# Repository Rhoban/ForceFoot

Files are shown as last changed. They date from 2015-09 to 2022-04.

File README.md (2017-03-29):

# Force foot

**Note that this is the v2 version, you can have a look at the v1 branch for
the previous release**

Here is a design of a robot foot using strain gauges as force sensors.
It was used by the Rhoban Football Club (France) during the RoboCup 2016.

If you have any question feel free to contact team@rhoban.com to ask it,
or open an issue on this repository.

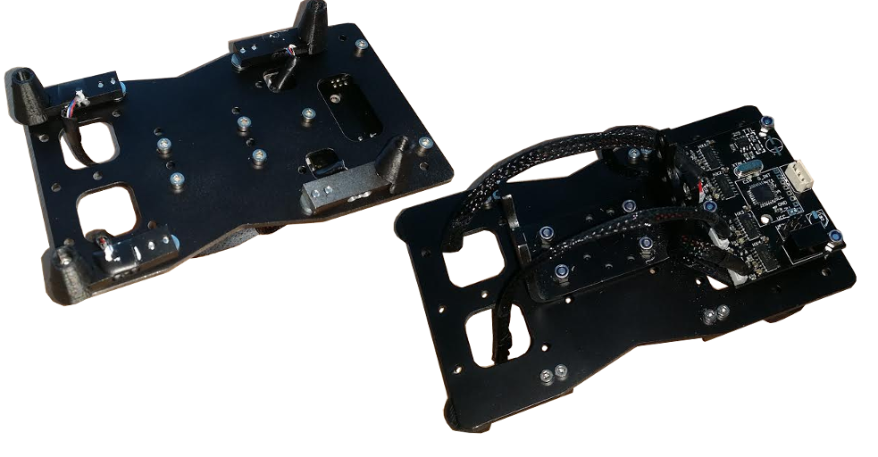
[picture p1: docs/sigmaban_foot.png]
force foot


## Repository contents

Here are the repository contents, you can click on below links to get the documentation:

* A [**mechanical design**](3d) suitable for Rhoban robots, that can be a good base
  to be adapted to fit your needs;
* Schematics for an  [**electronics board**](electronics) containing all the components to get
  the values from the sensors and communicate them through dynamixel;
* A [**firmware**](firmware) for the controller that is on the electronics.

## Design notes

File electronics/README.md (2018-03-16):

# Electronics

Here you'll find the schematics and (auto)routed board for sampling the gauge and communicate
through the dynamixel bus.

## Options

Some optional resistors on this board can be used to support dynamixel TTL/485 and 3/4 wire
gauges:

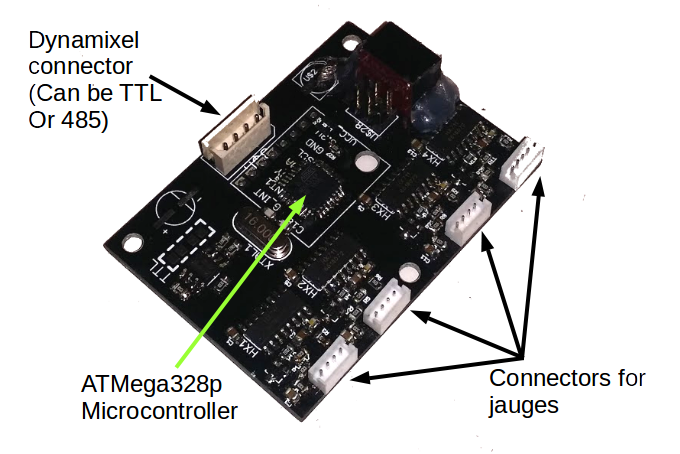
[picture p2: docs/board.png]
optional features


### Dynamixel RS485 or TTL

The two resistors (see yellow zones above) are only required if you want to use TTL Dynamixel.
In this case, you can solder a 3-pin connector on the dynamixel zone and it will do the job.

Actually, the A pin of the RS485 transciever is exactly the same as TTL when driving the line.
this change brings the B pin at VCC/2 (which should be 2.5V), so that when listening an high
A is 2.5V above B and a low A is 2.5V below B, which meets the RS485 requirements and makes
the MAX485 (or ST485) chip able to listen TTL, while perfectly respecting its specifications.

### 3-wire or 4-wire gauges

There is two main kind of mounting, half-bridges, which looks like that:

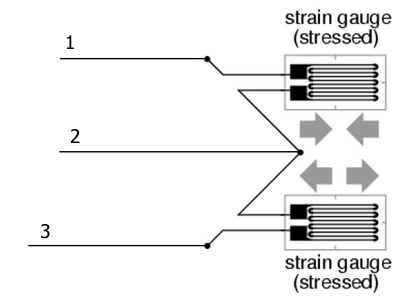
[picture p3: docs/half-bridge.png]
half-bridge


Here, there is three wire, so you'll have to compare the voltage value to 2.5V, this is why you
should solder the resistors (see cyan part of the above image) which will bring A- to V+/2 and
solder the third wire to A+.

The another option is a full-bridge:

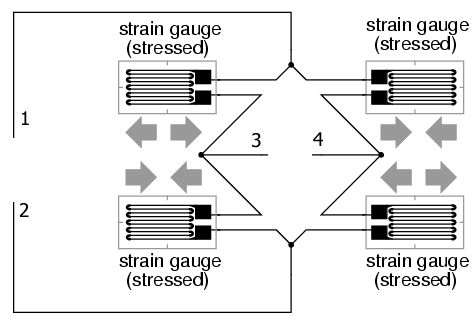
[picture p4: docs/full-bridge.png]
full-bridge


We recommend this system since it is more accurate and robust. You'll have to solder the two
wires to A- and A+. The order of soldering doesn't really matter, since it will only affect the
sign of the measured value.

## Components

Here's a list of components you'll need to build the board with example links for buying them

### Controller

* ATmega328PB
* 16 Mhz HC49US quartz

### Resistors (all are 0805 package)

* 22 ohms
* 3 Kohms
* 8.2 Kohms
* 20 Kohms

### Capacitors (all are 0805 package)

* 1uF
* 0.2uF
* 22 pF

### Polar capacitor, for decoupling

* EEE1CA470SP: 47uF
* EEEFK1C221XP: 220uF

### Power 

You can buy a 7805, but we recommend using a switching instead, like the TRACO TSR 1-2450
to avoid intensive heating.

### ICs

The amps are HX711, a really widespread chip that is use in weight scales
This chips regulates the reference voltage for the amp, using an external
PNP transistor (SOT-23 package). S8550 or BC857B,215 can be used.

### Connectors for jauges

You can use any 1.5mm pitch connector you like. We recommend the
[JST-ZH 4P](https://fr.aliexpress.com/item/40-SETS-Mini-Micro-ZH-1-5-4-Pin-JST-Connector-with-Wires-Cables/32612842708.html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).

Note that the order of the pins, from left to right are:

    GND VCC A B

Which corresponds typically on cells to:

    BLACK RED WHITE GREEN

If you use only half bridge, do not connect the 3rd (white) pin, and solder the two
resistors that can apply VCC/2 on it.

[Continue through the docs with the firmware »](../firmware)

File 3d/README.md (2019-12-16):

# 3D design

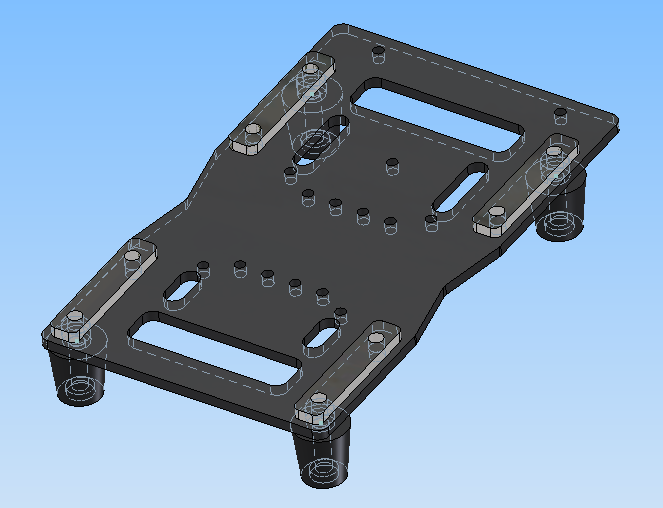
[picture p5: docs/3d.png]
3d


This is 3D designs for a foot. The files were created using Autodesk Inventor
2015 CAD software. If you are student, you can get a free version here:
http://www.autodesk.com/education/free-software/all

This design can be used as a reference or "as-is", if you decide to buy the
same gauges.

## Sourcing the gauges

The design is based on [Strain gauges](https://en.wikipedia.org/wiki/Strain_gauge).
You can buy the sensor itself separately, and also find it with mechanical
(mostly aluminium) shaft, we recommend this last option since it's not expansive
and already guarantee to have a correct bending.

The first thing you'll need is to get gauges fitting your needs, we used 5kg
nominal, which is about the maximum weight that they should have to hold
separately.

You can buy low-cost ones from AliExpress,
eBay or any general purpose market place.

There is different gauges out there, we recommend suing
differential ones (featuring wheatstone bridge arrangement, 4 wires). 

## Cells of this design

The cells in this design are 40 kg nominal, made of steel with 2 M4 holes with
27mm spacing

They can be found under the reference "HL703" or "TAL230A"

* [eBay](http://www.ebay.fr/itm/40kg-Aluminium-Alloy-Portable-Rectangle-Kitchen-Scale-Weight-Sensor-Load-Cell-/311507964552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)
* [AliExpress](https://www.aliexpress.com/item/10pcs-40kg-weight-sensor-miniature-full-bridge-sensor-weighing-force-sensor-freeshipping/32498871281.html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,searchweb201602_5_10152_10065_10151_10068_5010015_10136_10137_10157_10060_10138_10155_10062_10156_437_10154_10056_10055_10054_10059_303_100031_10099_10103_10102_10101_10096_10147_10052_10053_10107_10050_10142_10051_5020016_10084_10083_10080_10082_10081_10177_10110_519_10111_10112_10113_10114_10180_10182_10185_10184_10078_10079_10073_10186_10123_142,searchweb201603_2,ppcSwitch_5&btsid=9c118a6d-5c25-40a6-ae97-44e3d203d671&algo_expid=1c5b80d4-c289-412d-ace7-c203356e1b79-17&algo_pvid=1c5b80d4-c289-412d-ace7-c203356e1b79)

## Foot part

### OnShape model

You can check out the Sigmaban humanoid model on OnShape to see the current mounting
of the Rhoban team foot force sensors:

* [OnShape Sigmaban public assembly](https://cad.onshape.com/documents/f3bdef32bffd81536fce83d1/v/779c691df8f135bba01eead1/e/a530b1889ee09acb5e1d7ff9)

### Autodesk (old)

The `foot.ipt` represents the foot plate, we recommend adjusting
the holes to fix it to the rest of your robot.

When printing it, you may fill this part with a reasonable amount of material.

[Continue through the docs with electronics »](../electronics)

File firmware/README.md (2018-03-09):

# Firmware

You will need an ICSP/ISP tool that uses the the 6-pin AVR header. We recommend
that you use the AVR ISP MkII. You can also use Arduino Uno as ISP.

## Fuses

The first step is configuring the fuses, in order to configure it to use the
external 16Mhz quartz. You can run the fuse.sh script:

    ./fuse-m328p.sh

Alternatively, you can use:

    ./fuse-m328pb.sh

For the ATmega328PB

This assumes you use the AVR ISP MkII, you can however change this script according
to your hardware.

## Building

First, edit `Makefile.config` to set `MCU_TARGET` to either `atmega328p` or `atmega328pb`.

To build the firmware, simply run:

    make

In the firmware directory

## Flashing

You can flash the firmware using the:

    make sendisp

Command, this still assumes AVR ISP MkII, you can edit the `Makefile` if you're
using other hardware.

## Protocol

The protocol is very straightforward, the board will appear exactly like a dynamixel 
servo, with a fancy model number and its own ID.

Model ID, ID and baudrate are not configurable on-the-fly with the current version, it
can be changed in the header of `src/main/main.c`. (Default model number 5004, id 123 and baudrate
1000000).

Each gauge value is a signed 24 bit value (least significant byte first), resulting in a total
of 3 bytes. Thus, the values of the four gauges are 12 bytes. These bytes can be read at the 
present position address of the dynamixel registers (``0x24`` / 36).

0x24 &rarr; 0x26 | 0x27 &rarr; 0x29 | 0x2a &rarr; 0x2c | 0x2d &rarr; 0x2f
-------|--------|-------|--------
Jauge 1 | Jauge 2 | Jauge 3 | Jauge 4

Here is an example of C code to read the values from one jauge:

```C
#include <stdint.h>

// The bytes are here LSB, the same order that it appear in the dynamixel
// (For instance, jauge 1 values are at dynamixel addresses 0x24 for b0, 0x25 
// for b1 and 0x26 for b2)
int32_t decode24bits(uint8_t b0, uint8_t b1, uint8_t b2)
{
    int32_t result = (
          (b2 << 24)
        | (b1 << 16)
        | (b0 << 8)
        ) >> 8;

    return result;
}
```

## How to use the values

### Calibration

Note that the values will not be trimmed, you'll have to write some code to get the 0-offset
and save it somewhere.

Then, you may want to calibrate each gauge using objects of known mass and applying linear 
regression on some values. You'll be then able to get the force, corresponding statically
to the weight applied to the robot on each gauge.

### Weight

An interresting value is the total weight of the robot, this can for instance tell you if your 
robot is on the floor or being handled.

### Weight ratio

The weight ratio is the distribution of the weight over the two foots. This can be used to know
what is the actual support phase during the walk (i.e which foot is actually on the ground supporting
the robot).

### Center of pressure

The center of pressure can be computed using barycenter of the points (the x,y of your cleats) weighted
with the force applied on it.

This result can be found using the sum of moments equation (a simimar problem is solved in [this
thesis, page 34](http://ir.library.oregonstate.edu/xmlui/bitstream/handle/1957/29797/SchaferChristopherA2005.pdf)).

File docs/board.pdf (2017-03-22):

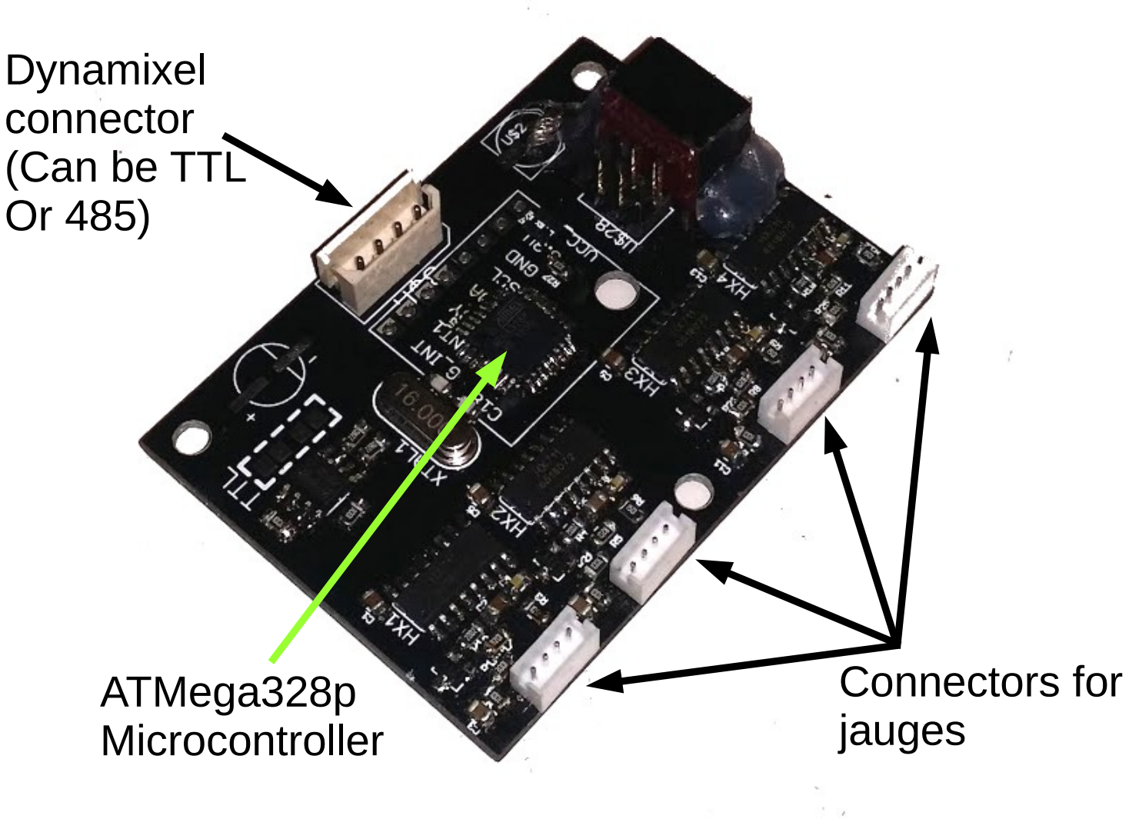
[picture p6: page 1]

Dynamixel
connector
(Can be TTL
Or 485)

Connectors for
jauges

ATMega328p
Microcontroller

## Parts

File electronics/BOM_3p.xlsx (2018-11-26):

 |  |  | Rhoban ForceFoot board TTL 3 pins edition
Item # | *Ref Des | *Qty | Manufacturer | *Mfg Part # | Description / Value | *Package | Type | Your Instructions / Notes
1 | R1, R13, R18, R19, R2, R20, R21, R22, R23, R24, R25, R26, R28, R29 | 14 | MULTICOMP | MCSR08X3001FTL | Resistor 3K | 0805 | SMD | Farnell : 2074431
2 | R10, R16, R4, R7 | 4 | MULTICOMP | MCSR08X2002FTL | Resistor 20k | 0805 | SMD | Farnell : 2074395
3 | R11, R17, R5, R8 | 4 | MULTICOMP | MCSR08X8201FTL | Resistor 8.2k | 0805 | SMD | Farnell : 2074518
4 | R14, R15 | 2 | MULTICOMP | MCWR08X22R0FTL | Resistor 22 Ohms | 0805 | SMD | Farnell : 2446926
5 | R12, R3, R6, R9 | 4 | MULTICOMP | MCSR08X1001FTL | Resistor 1K | 0805 | SMD | Farnell : 2074332RL
6 | R27 | 1 | MULTICOMP | MCSR08X1002FTL | Resistor 10k | 0805 | SMD | Farnell :2074334RL
7 | C1, C10, C11, C13, C14, C15, C2, C3, C5, C6, C7, C9 | 12 | TDK | C2012X5R1E105K125AA | Capacitor 1uF | 0805 | SMD | Farnell : 2525136RL
8 | C12, C16, C4, C8 | 4 | MURATA | GCM21BR72A104KA37K | Capacitor 0.1uF | 0805 | SMD | Farnell : 2688486RL
9 | C17, C18 | 2 | MULTICOMP | MC0805N220J201CT | Capacitor 22pF | 0805 | SMD | Farnell : 1759489RL
10 | U$4 | 1 | PANASONIC | EEEFK1C221XP | Capacitor 220uF | - | SMD | Farnell : 1850103
11 | U$2 | 1 | PANASONIC | EEE1CA470SP | Capacitor 47uF | - | SMD | Farnell : 9696946
12 | XTAL1 | 1 | ABRACON | ABLS-16.000MHZ-B2-T. | Crystal 16Mhz | HC-49US | Thru-Hole | Farnell : 7940506
13 | U$10, U$13, U$3, U$7 | 4 | JST | B4B-ZR(LF)(SN) | Connector 4 pins JST-ZH | - | Thru-Hole | Farnell : 9491791
14 | U2 | 1 | MICROCHIP | ATMEGA328PB-AU | ATmega328PB-AU microcontroller | TQFP-32 | SMD | Farnell : 2523203
15 | HX1, HX2, HX3, HX4 | 4 | AVIA SEMICONDUCTOR | HX711 | HX711 IC amp | SOIC16 | SMD | -
16 | DXL | 1 | MOLEX | 22-03-5035 (3 PIN connector) | Dynamixel Connector | - | Thru-Hole | 9979620
17 | U$1, U$12, U$6, U$9 | 4 | ON SEMICONDUCTOR | KST92MTF | PNP transistor | SOT-23 | SMD | Farnell : 1095136
18 | REG | 1 | TRACOPOWER | TSR 1-2450 | 5V 1A TRACOPOWER Regulator | - | Thru-Hole | Farnell : 1696320
19 | ISP | 1 | MULTICOMP | 2213S-06G | 2x3 0.1’’ male header | - | Thru-Hole | Farnell : 1593440
20 | MAX485 | 1 | STMICROELECTRONICS | ST485BDR | Transceiver RS422/RS485 | SOIC8 | SMD | Farnell : 1564306
Click for Instructions on How to Create a BOM (https://www.pcbway.com/blog/PCB_Assembly/How_to_Build_a_BOM__Bill_Of_Materials_.html)

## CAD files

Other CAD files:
3d/cell.ipt
3d/cleat.ipt
3d/foot.iam
3d/foot.ipt
3d/jauge.ipt
3d/nylon_spacer.ipt

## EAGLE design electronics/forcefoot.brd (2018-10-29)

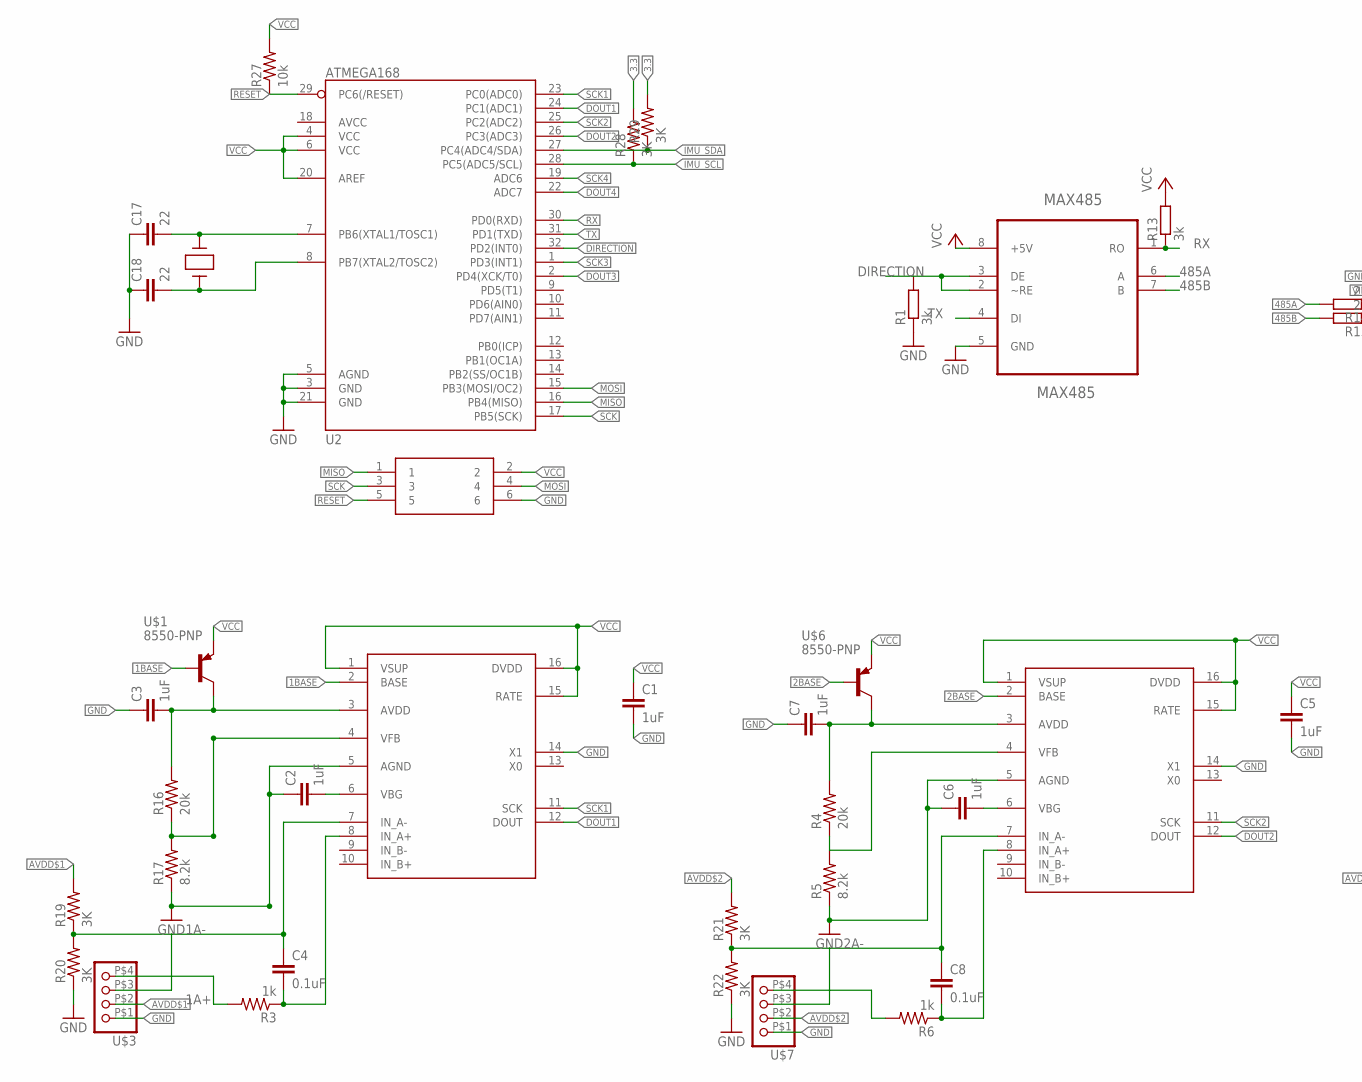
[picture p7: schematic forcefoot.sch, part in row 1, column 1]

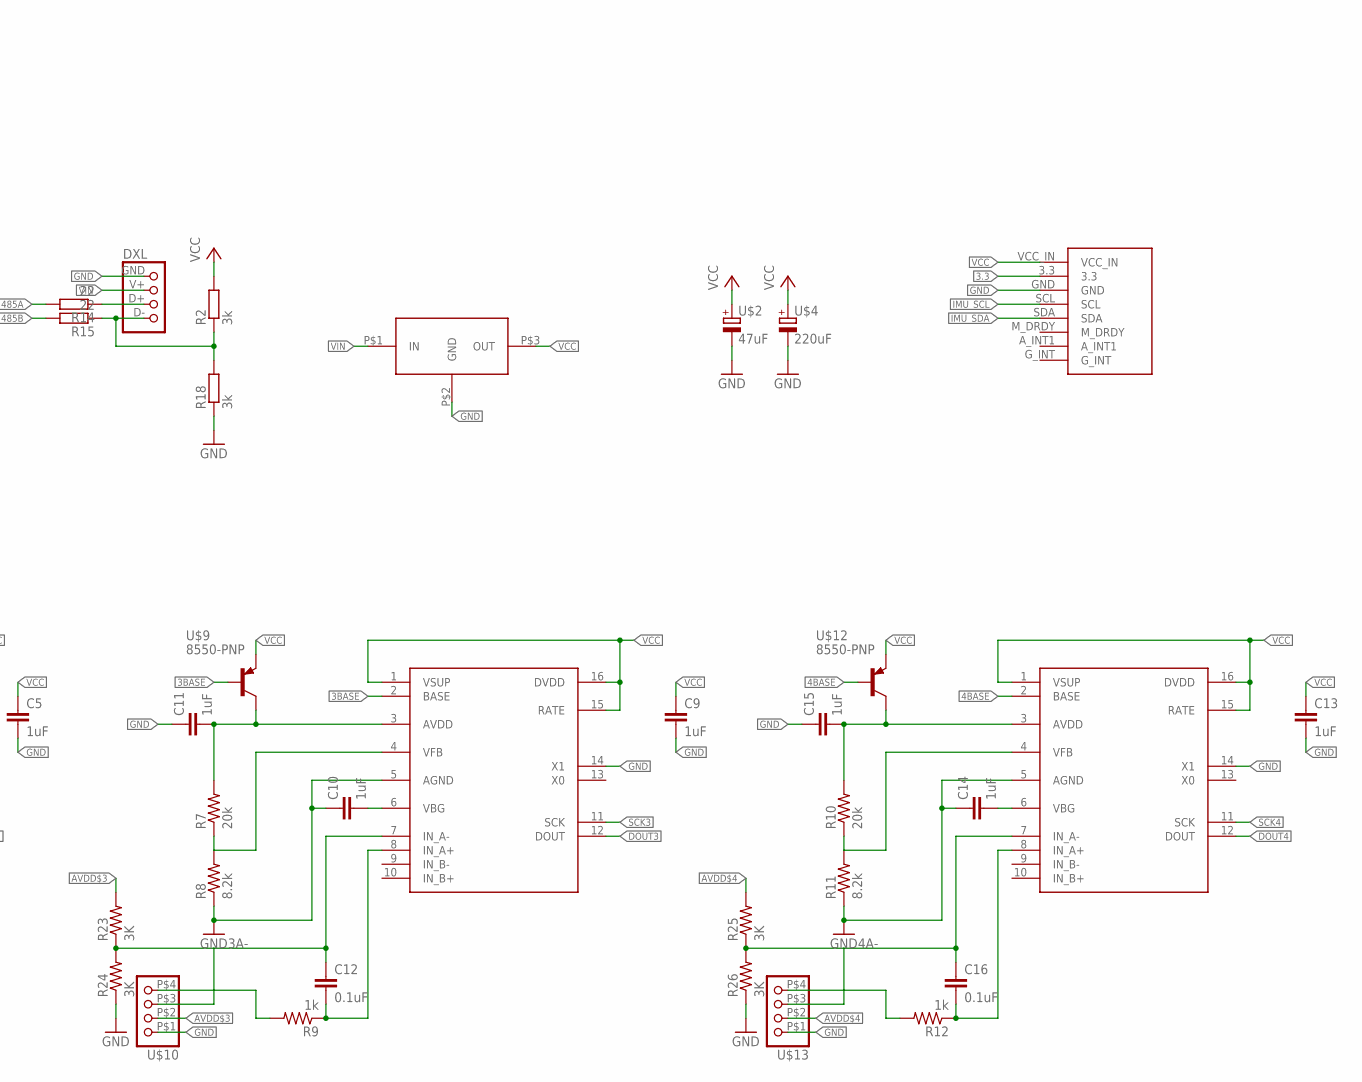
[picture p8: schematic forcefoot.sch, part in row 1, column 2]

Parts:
C1, C2, C3, C5, C6, C7, C9, C10, C11, C13, C14, C15: 1uF; 0805; FARNELL 2525136RL
C4, C8, C12, C16: 0.1uF; 0805; FARNELL 2688486RL
C17, C18: 22; C0603; FARNELL 1759489RL
DXL: CONNEC_1X04_485; CONNEC_485; FARNELL 1104204 OR 9979620
HX1, HX2, HX3, HX4: HX711SO16; SO16; FARNELL HX711
IMU: GY-85
ISP: CONNEC_2X03; FARNELL 1593440
MAX485: MAX485; SO8; FARNELL 1564306
R1, R2, R13, R18: 3k; R0805; FARNELL 2074431
R3, R6, R9, R12: 1k; 0805; FARNELL 2074332RL
R4, R7, R10, R16: 20k; 0805; FARNELL 2074395
R5, R8, R11, R17: 8.2k; 0805; FARNELL 2074518
R14, R15: 22; R0805; FARNELL 2446926
R19, R20, R21, R22, R23, R24, R25, R26, R28, R29: 3K; 0805; FARNELL 2074431
R27: 10k; 0805; FARNELL 2074334RL
REG: REG_5V; TRACOPOWER; FARNELL 1696320
U2: ATMEGA168; TQFP32-08; FARNELL 2523203
U$1, U$6, U$9, U$12: 8550-PNP; SOT-23; FARNELL 1095136
U$2: 47uF; PANASONIC_D; FARNELL 9696946
U$3, U$7, U$10, U$13: CONNEC_1X041.5; 4P1.5; FARNELL 9491791
U$4: 220uF; PANASONIC_D8; FARNELL 1850103
XTAL1: QUARTZ; HC49US; FARNELL 7940506

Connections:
1A+: R3.2, U$3.P$4 (4)
1A-: C4.1, HX1.7 (IN_A-), R19.1, R20.2, U$3.P$3 (3)
1BASE: HX1.2 (BASE), U$1.1 (B)
2A-: C8.1, HX2.7 (IN_A-), R21.1, R22.2, U$7.P$3 (3)
2BASE: HX2.2 (BASE), U$6.1 (B)
3.3: IMU.3.3, R28.2, R29.2
3A-: C12.1, HX3.7 (IN_A-), R23.1, R24.2, U$10.P$3 (3)
3BASE: HX3.2 (BASE), U$9.1 (B)
4A-: C16.1, HX4.7 (IN_A-), R25.1, R26.2, U$13.P$3 (3)
4BASE: HX4.2 (BASE), U$12.1 (B)
485A: MAX485.6 (A), R14.2
485B: MAX485.7 (B), R15.2
AVDD$1: C3.2, HX1.3 (AVDD), R16.2, R19.2, U$1.3 (C), U$3.P$2 (2)
AVDD$2: C7.2, HX2.3 (AVDD), R4.2, R21.2, U$6.3 (C), U$7.P$2 (2)
AVDD$3: C11.2, HX3.3 (AVDD), R7.2, R23.2, U$9.3 (C), U$10.P$2 (2)
AVDD$4: C15.2, HX4.3 (AVDD), R10.2, R25.2, U$12.3 (C), U$13.P$2 (2)
DIRECTION: MAX485.2 (~RE), MAX485.3 (DE), R1.2, U2.32 (PD2(INT0))
DOUT1: HX1.12 (DOUT), U2.24 (PC1(ADC1))
DOUT2: HX2.12 (DOUT), U2.26 (PC3(ADC3))
DOUT3: HX3.12 (DOUT), U2.2 (PD4(XCK/T0))
DOUT4: HX4.12 (DOUT), U2.22 (ADC7)
GND: C1.2, C2.1, C3.1, C5.2, C6.1, C7.1, C9.2, C10.1, C11.1, C13.2, C14.1, C15.1, C17.1, C18.1, DXL.GND (1), HX1.5 (AGND), HX1.14 (X1), HX2.5 (AGND), HX2.14 (X1), HX3.5 (AGND), HX3.14 (X1), HX4.5 (AGND), HX4.14 (X1), IMU.GND, ISP.6, MAX485.5 (GND), R1.1, R5.1, R8.1, R11.1, R17.1, R18.1, R20.1, R22.1, R24.1, R26.1, REG.P$2 (GND), U2.3 (GND), U2.5 (AGND), U2.21 (GND), U$2.-, U$3.P$1 (1), U$4.-, U$7.P$1 (1), U$10.P$1 (1), U$13.P$1 (1)
IMU_SCL: IMU.SCL, R28.1, U2.28 (PC5(ADC5/SCL))
IMU_SDA: IMU.SDA, R29.1, U2.27 (PC4(ADC4/SDA))
INAP$1: C4.2, HX1.8 (IN_A+), R3.1
INAP$2: C8.2, HX2.8 (IN_A+), R6.1
INAP$3: C12.2, HX3.8 (IN_A+), R9.1
INAP$4: C16.2, HX4.8 (IN_A+), R12.1
MISO: ISP.1, U2.16 (PB4(MISO))
MOSI: ISP.4, U2.15 (PB3(MOSI/OC2))
unnamed: C2.2, HX1.6 (VBG)
unnamed: C6.2, HX2.6 (VBG)
unnamed: R6.2, U$7.P$4 (4)
unnamed: C10.2, HX3.6 (VBG)
unnamed: R9.2, U$10.P$4 (4)
unnamed: C14.2, HX4.6 (VBG)
unnamed: R12.2, U$13.P$4 (4)
unnamed: C17.2, U2.7 (PB6(XTAL1/TOSC1)), XTAL1.2
unnamed: C18.2, U2.8 (PB7(XTAL2/TOSC2)), XTAL1.1
RESET: ISP.5, R27.1, U2.29 (PC6(/RESET))
RS+: DXL.D+ (3), R14.1
RS-: DXL.D- (4), R2.1, R15.1, R18.2
RX: MAX485.1 (RO), R13.1, U2.30 (PD0(RXD))
SCK: ISP.3, U2.17 (PB5(SCK))
SCK1: HX1.11 (SCK), U2.23 (PC0(ADC0))
SCK2: HX2.11 (SCK), U2.25 (PC2(ADC2))
SCK3: HX3.11 (SCK), U2.1 (PD3(INT1))
SCK4: HX4.11 (SCK), U2.19 (ADC6)
TX: MAX485.4 (DI), U2.31 (PD1(TXD))
VCC: C1.1, C5.1, C9.1, C13.1, HX1.1 (VSUP), HX1.15 (RATE), HX1.16 (DVDD), HX2.1 (VSUP), HX2.15 (RATE), HX2.16 (DVDD), HX3.1 (VSUP), HX3.15 (RATE), HX3.16 (DVDD), HX4.1 (VSUP), HX4.15 (RATE), HX4.16 (DVDD), IMU.VCC_IN, ISP.2, MAX485.8 (+5V), R2.2, R13.2, R27.2, REG.P$3 (OUT), U2.4 (VCC), U2.6 (VCC), U2.20 (AREF), U$1.2 (E), U$2.+, U$4.+, U$6.2 (E), U$9.2 (E), U$12.2 (E)
VFB$1: HX1.4 (VFB), R16.1, R17.2
VFB$2: HX2.4 (VFB), R4.1, R5.2
VFB$3: HX3.4 (VFB), R7.1, R8.2
VFB$4: HX4.4 (VFB), R10.1, R11.2
VIN: DXL.V+ (2), REG.P$1 (IN)

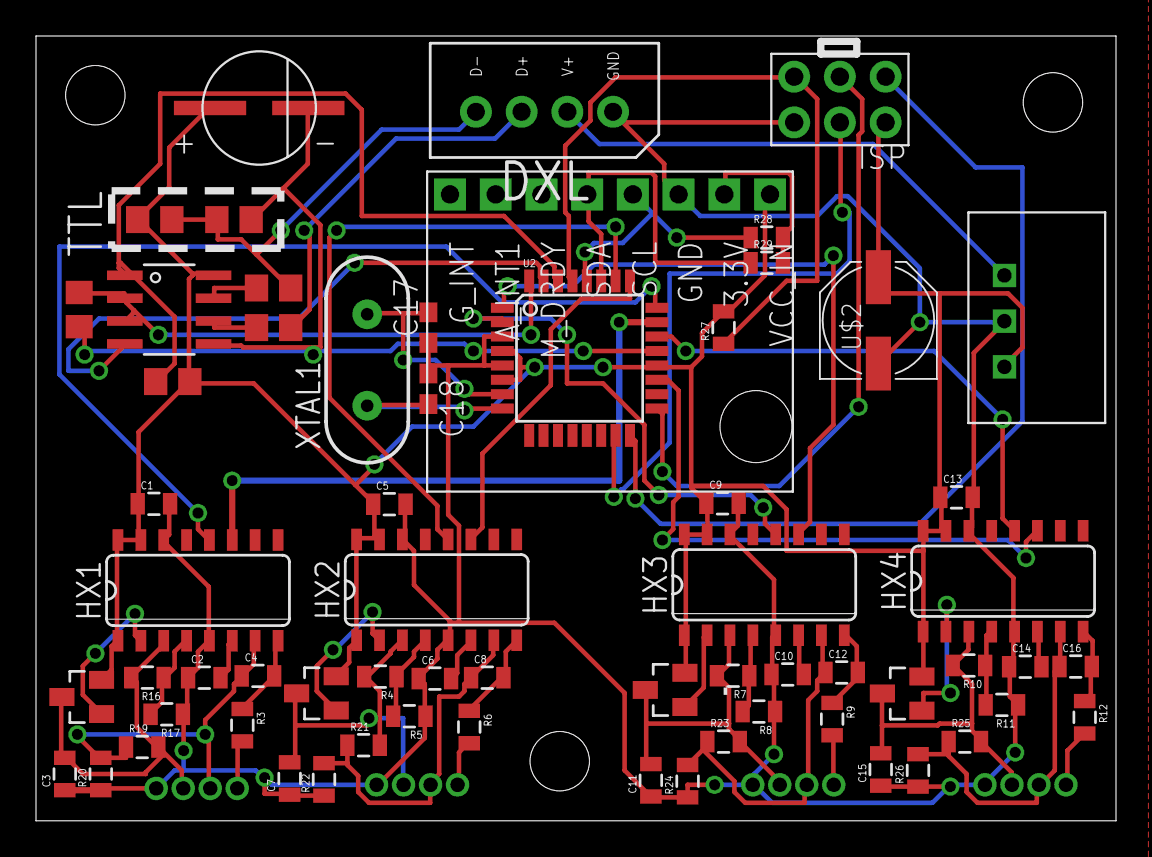
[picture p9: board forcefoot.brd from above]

Board: 2 copper layers, 60.0 x 43.6 mm, 71 parts (0 on the bottom side), 55 nets.

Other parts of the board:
U$11, U$14, U$16: STAND-OFF

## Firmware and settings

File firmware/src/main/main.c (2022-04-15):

#include <stdio.h>
#include <string.h>
#include <stdlib.h>
#include <avr/io.h>
#include <util/delay.h>
#include <avr/interrupt.h>
#include <avr/pgmspace.h> 
#include <uart/uart.h>
#include <avr/sleep.h>
#include <avr/wdt.h>
#include <terminal/terminal.h>
#include <uart/dir.h>
#include <dxl/dxl.h>
#include <dxl/registers.h>
#include "hx711.h"
#include "led.h"

#define DXL_MODEL               5004
#define DXL_ID                  124
// #define DXL_RETURN_DELAY        250

// Dynamixel registers
struct dxl_registers registers;

// Is this id handled by the module ?
ui8 dxl_check_id(ui8 id)
{
    return (id == DXL_ID);
}

// Write in some registers
void dxl_write_data(ui8 id, ui8 addr, ui8 *values, ui8 length)
{
    // XXX: Ignored
}

static void putValue(int32_t val, unsigned char *data)
{
    data[0] = (val >> 0)&0xff;
    data[1] = (val >> 8)&0xff;
    data[2] = (val >> 16)&0xff;
}

// A register is read
void dxl_read_data(ui8 id, ui8 addr, ui8 *values, ui8 length, ui8 *error)
{
    *error = 0;

#ifdef DXL_RETURN_DELAY
    _delay_us(DXL_RETURN_DELAY);
#endif

    int k;
    unsigned char *rvalues = &registers.ram.presentPosition;
    for (k=0; k<4; k++) {
        putValue(hx711_values[k], rvalues+3*k);
    }

    memcpy(values, ((ui8*)&registers)+addr, length);
}

int main (void)
{
    wdt_disable();
    // Direction pin
    dir_set(0);
    dir_init();

    cli();
    // Initializing UART
    uart_init(UART_BAUD_SELECT_DOUBLE_SPEED(BAUDRATE, F_CPU));
    sei();
    
    // Registers
    registers.eeprom.id = DXL_ID;
    registers.eeprom.modelNumber = DXL_MODEL;
    registers.eeprom.firmwareVersion = 1;

    // Initializing DXL module
    dxl_init();

    // Initializing HX711s
    hx711_init();

    led_init();

    while (1) {
        // Reading the balances
        hx711_tick();

        // Reading serial data
        while (uart_available()) {
            ui8 c = uart_getc()&0xff;
            dxl_push_incoming_byte(c); 
        }
    }
}

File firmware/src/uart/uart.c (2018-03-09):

/*************************************************************************
Title:    Interrupt UART library with receive/transmit circular buffers
Author:   Peter Fleury <pfleury@gmx.ch>   http://jump.to/fleury
File:     $Id: uart.c,v 1.6.2.2 2009/11/29 08:56:12 Peter Exp $
Software: AVR-GCC 4.1, AVR Libc 1.4.6 or higher
Hardware: any AVR with built-in UART, 
License:  GNU General Public License 
          
DESCRIPTION:
    An interrupt is generated when the UART has finished transmitting or
    receiving a byte. The interrupt handling routines use circular buffers
    for buffering received and transmitted data.
    
    The UART_RX_BUFFER_SIZE and UART_TX_BUFFER_SIZE variables define
    the buffer size in bytes. Note that these variables must be a 
    power of 2.
    
USAGE:
    Refere to the header file uart.h for a description of the routines. 
    See also example test_uart.c.

NOTES:
    Based on Atmel Application Note AVR306
                    
LICENSE:
    Copyright (C) 2006 Peter Fleury

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
*************************************************************************/
#include <avr/io.h>
#include <avr/interrupt.h>
#include <avr/pgmspace.h>
#include <uart/uart.h>
#include <stdio.h>

/*
 *  constants and macros
 */

/* Enables half-duplex */
//#define HALF_DUPLEX

/* Enables PD2 as direction PIN */
//#define DIRECTION_PIN

/* size of RX/TX buffers */
#define UART_RX_BUFFER_MASK ( UART_RX_BUFFER_SIZE - 1)
#define UART_TX_BUFFER_MASK ( UART_TX_BUFFER_SIZE - 1)

#if ( UART_RX_BUFFER_SIZE & UART_RX_BUFFER_MASK )
#error RX buffer size is not a power of 2
#endif
#if ( UART_TX_BUFFER_SIZE & UART_TX_BUFFER_MASK )
#error TX buffer size is not a power of 2
#endif

#if defined(__AVR_AT90S2313__) \
 || defined(__AVR_AT90S4414__) || defined(__AVR_AT90S4434__) \
 || defined(__AVR_AT90S8515__) || defined(__AVR_AT90S8535__) \
 || defined(__AVR_ATmega103__)
 /* old AVR classic or ATmega103 with one UART */
 #define AT90_UART
 #define UART0_RECEIVE_INTERRUPT   SIG_UART_RECV
 #define UART0_TRANSMIT_INTERRUPT  SIG_UART_DATA
 #define UART0_STATUS   USR
 #define UART0_CONTROL  UCR
 #define UART0_DATA     UDR  
 #define UART0_UDRIE    UDRIE
#elif defined(__AVR_AT90S2333__) || defined(__AVR_AT90S4433__)
 /* old AVR classic with one UART */
 #define AT90_UART
 #define UART0_RECEIVE_INTERRUPT   SIG_UART_RECV
 #define UART0_TRANSMIT_INTERRUPT  SIG_UART_DATA
 #define UART0_STATUS   UCSRA
 #define UART0_CONTROL  UCSRB
 #define UART0_DATA     UDR 
 #define UART0_UDRIE    UDRIE
#elif  defined(__AVR_ATmega8__)  || defined(__AVR_ATmega16__) || defined(__AVR_ATmega32__) \
  || defined(__AVR_ATmega8515__) || defined(__AVR_ATmega8535__) \
  || defined(__AVR_ATmega323__)
  /* ATmega with one USART */
 #define ATMEGA_USART
 #define UART0_RECEIVE_INTERRUPT   SIG_UART_RECV
 #define UART0_TRANSMIT_INTERRUPT  SIG_UART_DATA
 #define UART0_STATUS   UCSRA
 #define UART0_CONTROL  UCSRB
 #define UART0_DATA     UDR
 #define UART0_UDRIE    UDRIE
 #define UART0_TXCIE    TXCIE
#elif defined(__AVR_ATmega163__) 
  /* ATmega163 with one UART */
 #define ATMEGA_UART
 #define UART0_RECEIVE_INTERRUPT   SIG_UART_RECV
 #define UART0_TRANSMIT_INTERRUPT  SIG_UART_DATA
 #define UART0_STATUS   UCSRA
 #define UART0_CONTROL  UCSRB
 #define UART0_DATA     UDR
 #define UART0_UDRIE    UDRIE
#elif defined(__AVR_ATmega162__) 
 /* ATmega with two USART */
 #define ATMEGA_USART0
 #define ATMEGA_USART1
 #define UART0_RECEIVE_INTERRUPT   SIG_USART0_RECV
 #define UART1_RECEIVE_INTERRUPT   SIG_USART1_RECV
 #define UART0_TRANSMIT_INTERRUPT  SIG_USART0_DATA
 #define UART1_TRANSMIT_INTERRUPT  SIG_USART1_DATA
 #define UART0_STATUS   UCSR0A
 #define UART0_CONTROL  UCSR0B
 #define UART0_DATA     UDR0
 #define UART0_UDRIE    UDRIE0
 #define UART1_STATUS   UCSR1A
 #define UART1_CONTROL  UCSR1B
 #define UART1_DATA     UDR1
 #define UART1_UDRIE    UDRIE1
#elif defined(__AVR_ATmega64__) || defined(__AVR_ATmega128__) || defined(__AVR_ATmega1284P__) || defined(__AVR_ATmega328PB__)
 /* ATmega with two USART */
 #define ATMEGA_USART0
 #define ATMEGA_USART1
 #define UART0_RECEIVE_INTERRUPT   SIG_UART0_RECV
 #define UART1_RECEIVE_INTERRUPT   SIG_UART1_RECV
 #define UART0_TRANSMIT_INTERRUPT  SIG_UART0_DATA
 #define UART1_TRANSMIT_INTERRUPT  SIG_UART1_DATA
 #define UART0_STATUS   UCSR0A
 #define UART0_CONTROL  UCSR0B
 #define UART0_DATA     UDR0
 #define UART0_UDRIE    UDRIE0
 #define UART1_STATUS   UCSR1A
 #define UART1_CONTROL  UCSR1B
 #define UART1_DATA     UDR1
 #define UART1_UDRIE    UDRIE1
 #define UART0_TXCIE    TXCIE0
 
 #define USART_UDRE_vect USART0_UDRE_vect
 #define USART_RXC_vect USART0_RX_vect
 #define USART_TXC_vect USART0_TX_vect
 #define USART1_RXC_vect USART1_RX_vect
 #define USART1_TXC_vect USART1_TX_vect
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

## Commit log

2015-09-16 Adding electronics
    [forcefoot.brd, forcefoot.sch]
2015-09-16 Board view
2015-09-16 3D design
    [assembly.iam, board.ipt, cleat.ipt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]
2015-10-27 Tying AGND to GND
    [forcefoot.brd, forcefoot.sch]
2015-10-27 Routable 8dof version
    [forcefoot.brd, forcefoot.sch]
2015-10-27 Adding clock, tweaking placing
    [forcefoot.brd, forcefoot.sch]
2015-10-27 Using 1.5mm 4p connectors
    [forcefoot.brd, forcefoot.sch]
2015-10-27 Tying B-/B+ to ground
    [forcefoot.brd, forcefoot.sch]
2015-11-17 Update schema
    [forcefoot.brd, forcefoot.sch]
2016-03-29 Atmega+GY-85 version
    [forcefoot.brd, forcefoot.sch]
2017-03-22 Tweaking for v2
    [forcefoot.brd, forcefoot.sch]
2017-05-19 Fixing r value
    [forcefoot.brd, forcefoot.sch]
2017-05-22 Fixing vin -> vcc for mcu
    [forcefoot.brd, forcefoot.sch]
2017-05-22 Fixing connections
    [forcefoot.brd, forcefoot.sch]
2017-05-31 Improving names and silk
    [forcefoot.brd, forcefoot.sch]
2018-03-09 Adding support for m328pb fuses
2018-03-16 TTL silk
    [forcefoot.brd]
2018-08-30 Adding FARNELL attributes and writing BOM
    [BOM.xlsx, forcefoot.brd, forcefoot.sch]
2018-10-29 BOM for 3p
    [BOM_3p.xlsx]
2019-12-16 Details about load cells and sigmaban public assembly
2022-04-15 There is no led

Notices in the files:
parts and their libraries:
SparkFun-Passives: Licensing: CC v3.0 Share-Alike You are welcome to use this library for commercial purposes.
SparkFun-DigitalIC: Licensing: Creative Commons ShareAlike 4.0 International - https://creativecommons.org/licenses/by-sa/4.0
